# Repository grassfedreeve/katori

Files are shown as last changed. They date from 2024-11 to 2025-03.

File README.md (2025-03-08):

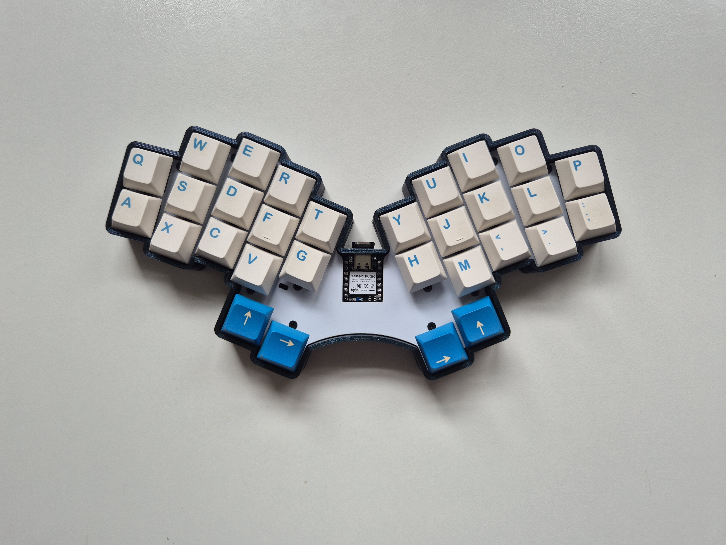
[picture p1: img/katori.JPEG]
katori


# katori
30-key wireless topre/ec hummingbird keyboard based on the [rufous](https://github.com/jcmkk3/trochilidae) & [topreviung](https://gitlab.com/lpgalaxy/topreviung) 
---- 
named after katori senkō mosquito coils that inspired the original conical spring design for topre switches, as well as katori's translation to bird as homage to the hummingbird.

## Status
Revision 1 has been built and tested. Had design error fixed in r2 but yet to be officially ordered

## Manufacturing

Can be hand soldered or ordered assembled using assembly files

Currently setup to use a 1.2mm aluminum single layer pcb as the plate

- [PCB production files](./production/)
- [Plate files](./plate/)
- [Case files](./case)

## Parts needed
- 1 pcb
- 1 plate
- 1 case
- 1 seeed xiao compatible controller
- 30 1u EC housing + slider
- 30 Rubber domes
- 30 Conical springs
- 26 [m1.6 5mm full thread standoffs](https://www.aliexpress.com/item/1005004397115309.html) 
- 1 [3x6x5 tht reset switch](https://www.aliexpress.com/store/1103739763)
- 26 m1.6 3mm screws
- 6 m3 3mm screws

## BOM
- 1 PCM12SMTR - power switch
- 7 SMTSO3020MTJ - SMD solder nut
- 2 TSSOP-16 multiplexers
- 1 0603 1k resistor
- 13 0603 100k resistors
- 3 0603 100n capacitors
- 1 0603 220pF capacitor

**Optional**
- Silencing rings
- [450mah 601148 battery](https://www.aliexpress.com/item/32844347206.html)
- 1 PCM12SMTR - power switch

#### PCB Renders
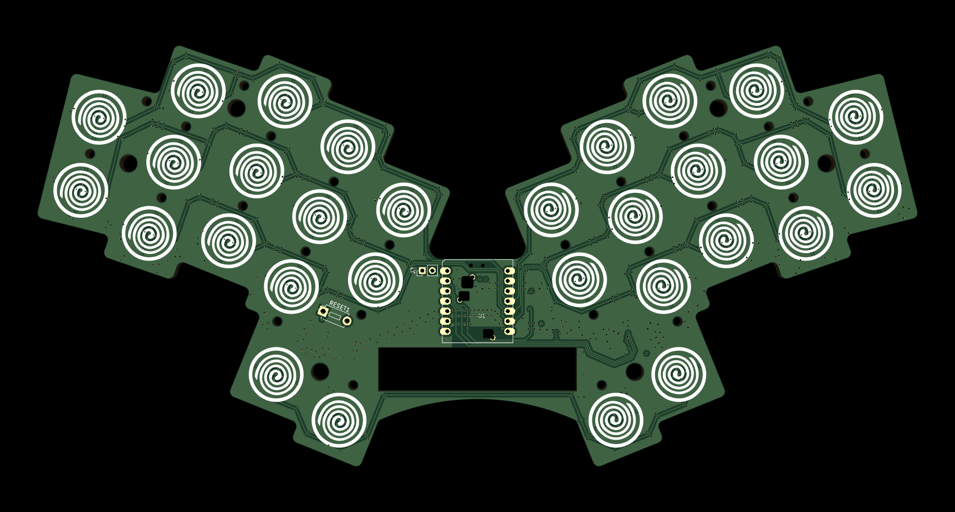
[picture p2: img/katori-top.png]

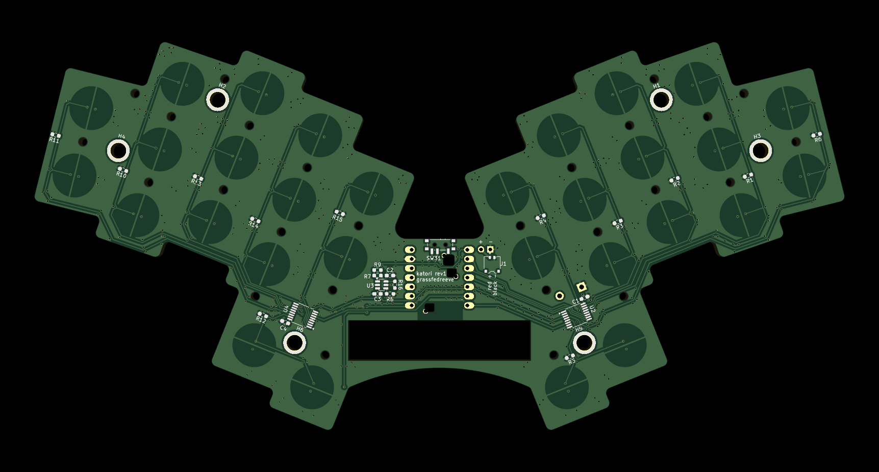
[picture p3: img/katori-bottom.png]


## Inspiration & Thanks
- jcmkk3's [rufous](https://github.com/jcmkk3/trochilidae#rufous) hummingbird variation, of which I used the Ergogen config and splay etc.
- pete johanson for his incredible help during the project and his [topreviung](https://gitlab.com/lpgalaxy/topreviung) keyboard, which was the basis of the schematic and entire EC portions.
- PJE66's original [hummingbird](https://github.com/PJE66/hummingbird) keyboard

## Acknowledgements 
Thank you to [PCBWay](https://www.pcbway.com/) for sponsoring this project!

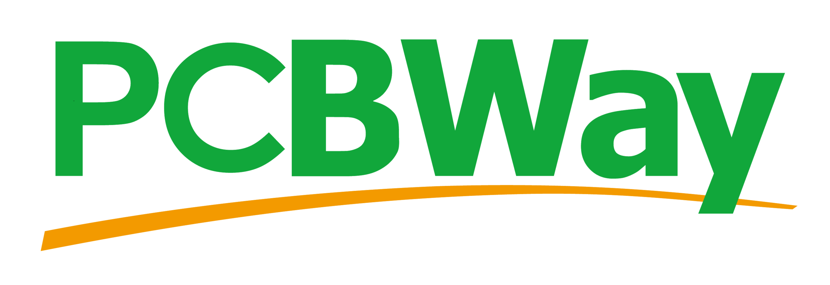
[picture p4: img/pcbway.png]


You can find and order the parts for this project on PCBWay using these links:

[pcb](https://www.pcbway.com/project/shareproject/Katori_30_key_wireless_topre_ec_hummingbird_keyboard_7163f60f.html)
[plate](https://www.pcbway.com/project/shareproject/Katori_Plate_a08691e4.html)

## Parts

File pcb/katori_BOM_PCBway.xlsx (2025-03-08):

 |  |  | xxxx xxxx xxxxx xxPCS BOM (Sample Bill of Materials)
Item # | *Designator | *Qty | Manufacturer | *Mfg Part # | Description / Value | *Package/Footprint | Type | Your Instructions / Notes
1 | J1 | 1 | JST | BM02B-ACHSS-GAN-ETF(LF)(SN) | 1x2P 2P ACH Gold 2 -25℃~+85℃ 2A 1 1.2mm Copper alloy Horizontal attachment SMD,P=1.2mm,Surface Mount，Right Angle Wire To Board Connector ROHS | SMD,P=1.2mm,Surface Mount，Right Angle | SMD
2 | U1 | 1 | Seeed-Studio | XIAO-BLE |  | SMD | DNS | DNP
3 | SW31 | 1 | C&K | PCM12SMTR | Standing paste Single Pole Double Throw (SPDT) 6V SMD Slide Switches ROHS | SMD | SMD
4 | H1,H2,H3,H4,H5,H6 | 7 | Sinhoo | SMTSO3020MTJ | SMD round nut | SMTSO3020MTJ | SMD
5 | U2,U4 | 2 | Texas Instruments | CD74HC4051PWR | TSSOP-16 Signal Switches, Multiplexers, Decoders ROHS | SSOP-16 | SMD
6 | R16 | 1 | UNI-ROYAL(Uniroyal Elec) | 0603WAF1004T5E | 100mW Thick Film Resistors 75V ±100ppm/℃ ±1% 1MΩ 0603 Chip Resistor - Surface Mount ROHS | 0603 | SMD | DNP
7 | R1,R2,R3,R4,R5,R6,R7,R10,R11,R12,R13,R14,R15 | 13 | UNI-ROYAL(Uniroyal Elec) | 0603WAF1003T5E | 100mW Thick Film Resistors 75V ±100ppm/℃ ±1% 100kΩ 0603 Chip Resistor - Surface Mount ROHS | 0603 | SMD
8 | R8 | 1 | UNI-ROYAL(Uniroyal Elec) | 0603WAF1001T5E | 100mW Thick Film Resistors 75V ±100ppm/℃ ±1% 1kΩ 0603 Chip Resistor - Surface Mount ROHS | 0603 | SMD
9 | C1,C2,C4 | 3 | Samsung Electro-Mechanics | CL10B104KB8NNNC | 50V 100nF X7R ±10% 0603 Multilayer Ceramic Capacitors MLCC - SMD/SMT ROHS | 0603 | SMD
10 | C3 | 1 | Samsung Electro-Mechanics | CL10B221KB8NNNC | 50V 220pF X7R ±10% 0603 Multilayer Ceramic Capacitors MLCC - SMD/SMT ROHS | 0603 | SMD
11 | U3 | 1 | Texas Instruments | OPA357AIDBVR | IC OPAMP VFB 1 CIRCUIT SOT23-6 | SOT-23-6 | SMD

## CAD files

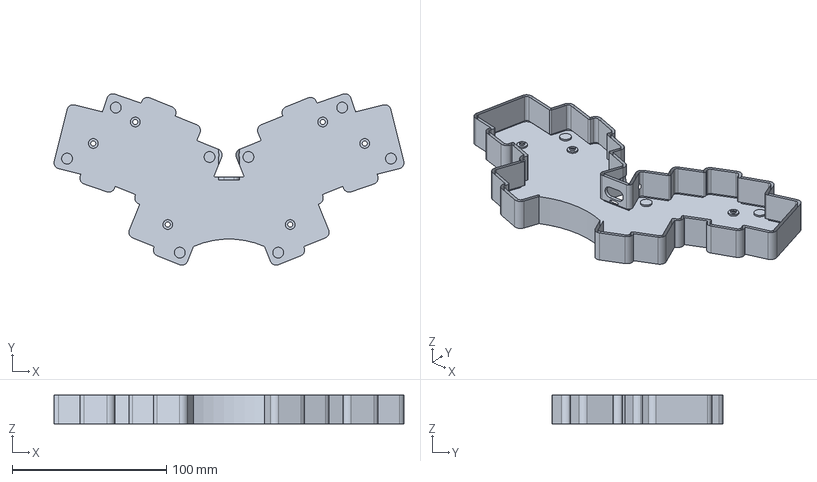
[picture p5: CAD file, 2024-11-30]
case/katori-case.step
226.9 x 111.1 x 18.6 mm

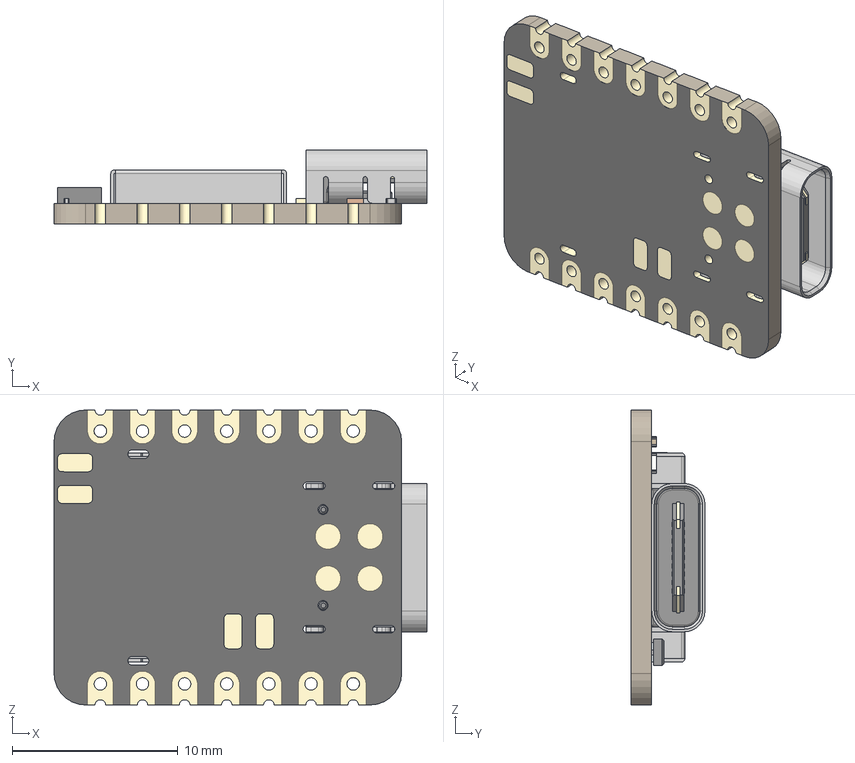
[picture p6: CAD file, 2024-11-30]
pcb/3d-models/XIAO-nRF52840 v15.step
22.5 x 4.46 x 17.8 mm
BOSS-EXTRUDE14_8_
BOSS-EXTRUDE7_4_
BOSS-EXTRUDE7_3_
BOSS-EXTRUDE14_4_
BOSS-EXTRUDE14_2_
BOSS-EXTRUDE14_11_
BOSS-EXTRUDE7_7_
BOSS-EXTRUDE14_9_
BOSS-EXTRUDE14_3_
BOSS-EXTRUDE14_7_
MIRROR2
BOSS-EXTRUDE14_5_
BOSS-EXTRUDE14_12_
BOSS-EXTRUDE7_8_
BOSS-EXTRUDE7_1_
BOSS-EXTRUDE14_10_
BOSS-EXTRUDE7_9_
BOSS-EXTRUDE14_6_
BOSS-EXTRUDE14_1_
BOSS-EXTRUDE7_6_
BOSS-EXTRUDE7_2_
CUT-EXTRUDE5
BOSS-EXTRUDE7_5_
Shield
Pins
CAP x 2
ANT1
Silkscreen
CAP 3
LED
USR
2 v1

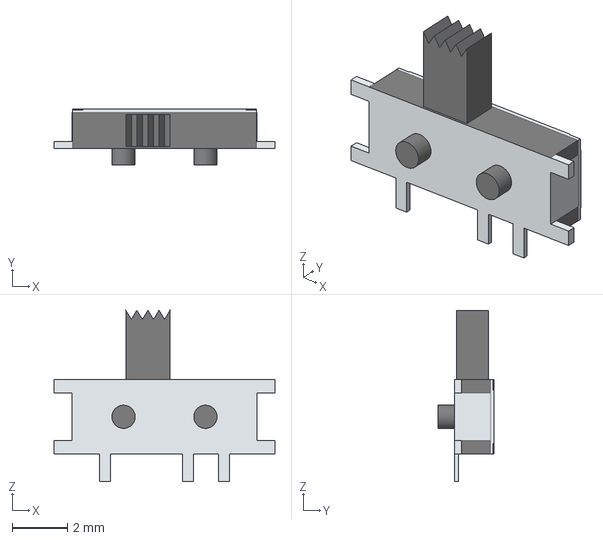
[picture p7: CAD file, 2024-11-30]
pcb/3d-models/Selector Switch - MSK1103.step
7.98 x 2.01 x 6.19 mm

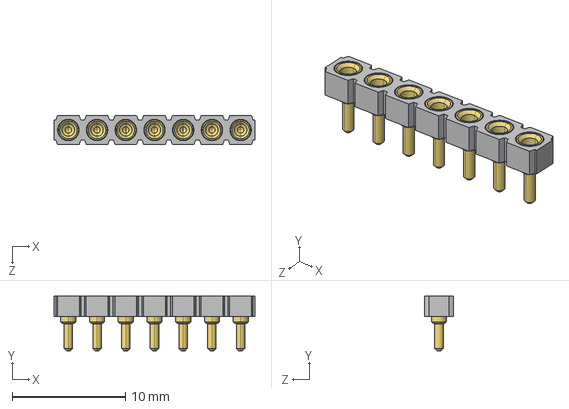
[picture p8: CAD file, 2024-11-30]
pcb/3d-models/mill-max-315-13-107-41-003000.STEP
17.8 x 4.83 x 2.54 mm
P3XX-11-011-00-000000_P307-11-011-00-000000

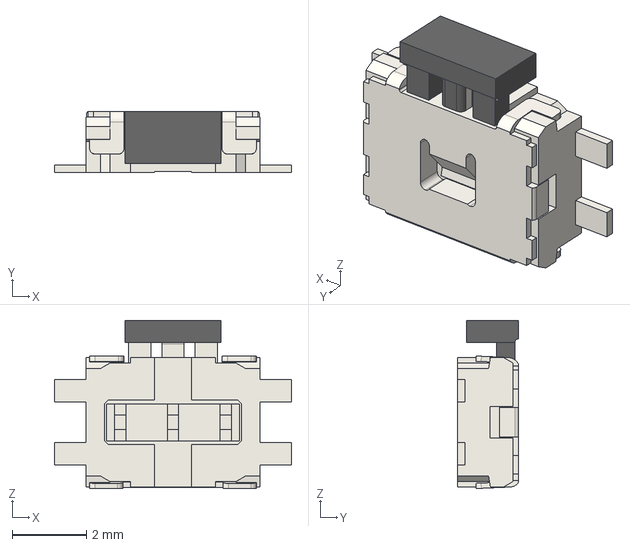
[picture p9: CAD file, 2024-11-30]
pcb/3d-models/EVQPU-JA-02K.STEP
6.40 x 1.65 x 4.54 mm

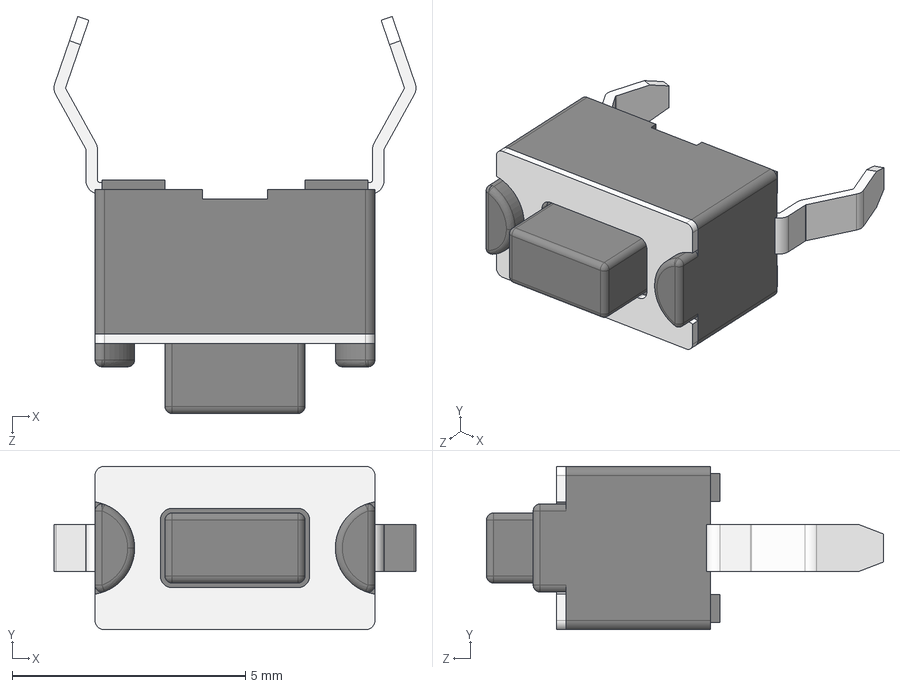
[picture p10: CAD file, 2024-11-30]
pcb/3d-models/3.5x6 THT.STEP
7.76 x 3.50 x 8.51 mm
Sheet Metal Part6 x 2

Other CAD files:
case/katori-case.stl

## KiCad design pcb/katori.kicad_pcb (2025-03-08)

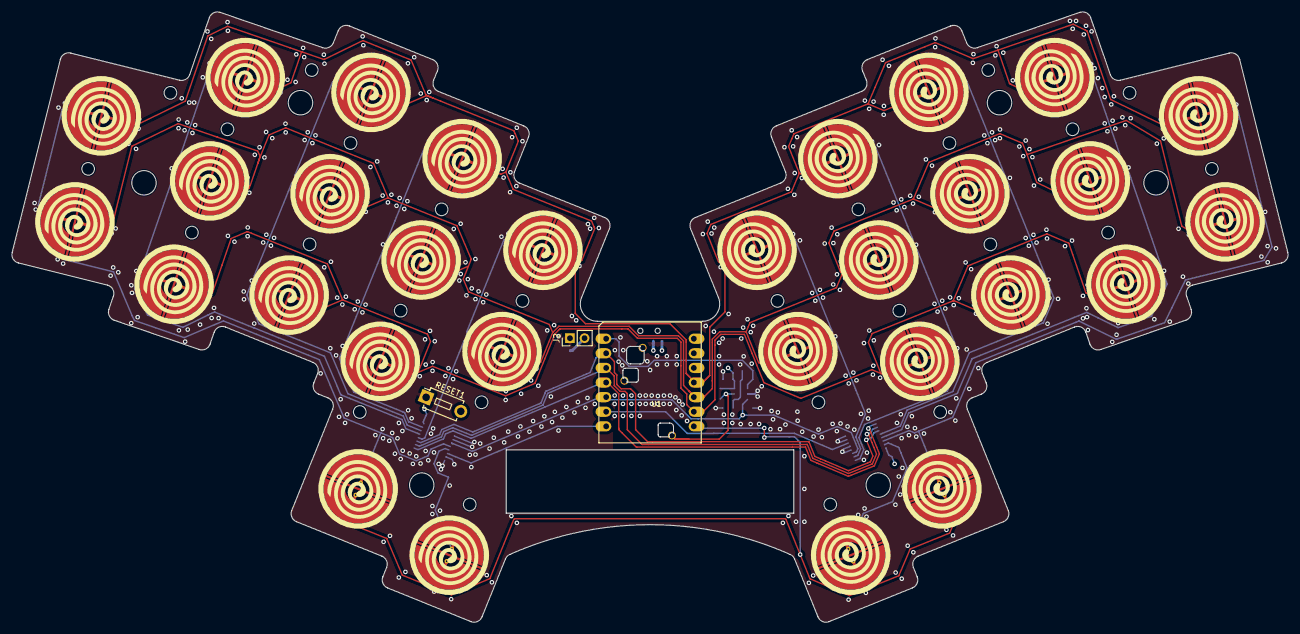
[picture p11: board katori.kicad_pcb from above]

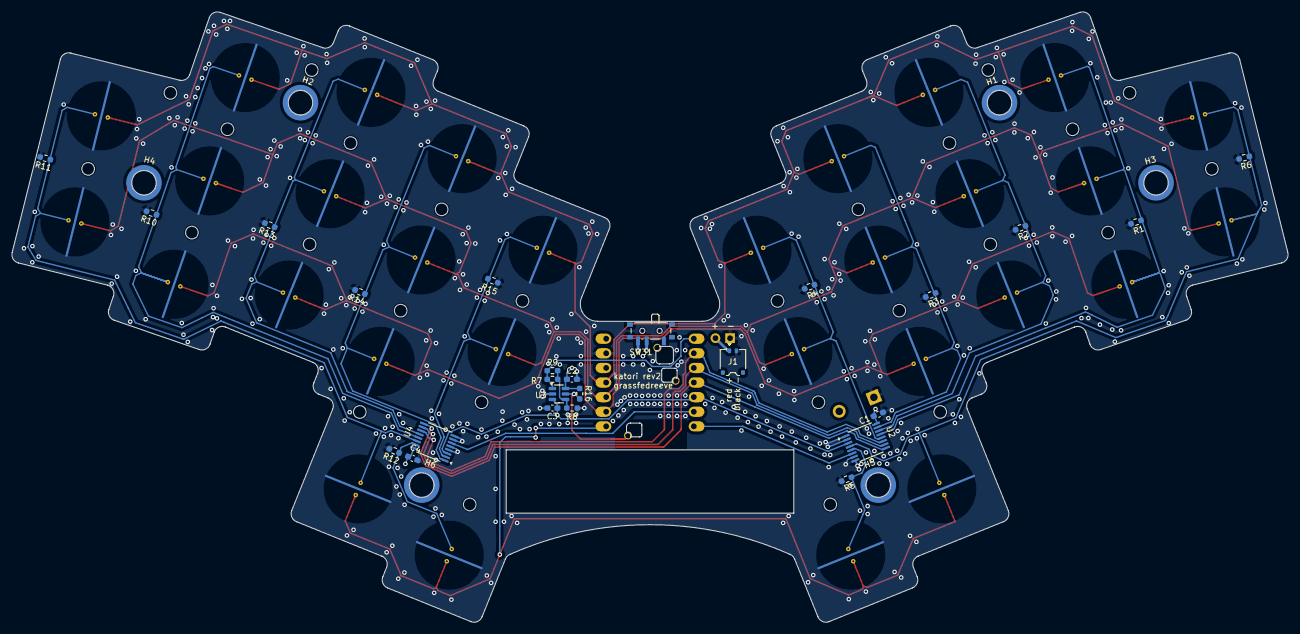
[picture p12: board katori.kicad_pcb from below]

Board: 4 copper layers, 221.9 x 106.1 mm, 98 parts (31 on the bottom side), 30 nets.

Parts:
BUMP1, BUMP2, BUMP3, BUMP4, BUMP5, BUMP6, BUMP7, BUMP8: MountingHole; Bumpon
C1, C2, C4: 100n; C_0603_1608Metric_Pad1.08x0.95mm_HandSolder
C3: 220pF; C_0603_1608Metric_Pad1.08x0.95mm_HandSolder
H1, H2, H3, H4, H5, H6: MountingHole; MountingHole_3mm_Pad_NonPTH_TopOnly
J1: JST ACH; JST_ACH_BM02B-ACHSS-GAN-ETF_1x02-1MP_P1.20mm_Vertical
J2: Solder; PinHeader_1x02_P2.54mm_Vertical
PH1, PH2, PH3, PH4, PH5, PH6, PH7, PH8, PH9, PH10, PH11, PH12, PH13, PH14, PH15, PH16, PH17, PH18, PH19, PH20, PH21, PH22, PH23, PH24, PH27, PH28: MountingHole; MountingHole_2.2mm_M2
R1, R2, R3, R4, R5, R6, R7, R10, R11, R12, R13, R14, R15: 100k; R_0603_1608Metric_Pad0.98x0.95mm_HandSolder
R8: 1k; R_0603_1608Metric_Pad0.98x0.95mm_HandSolder
R9: DNP; R_0603_1608Metric_Pad0.98x0.95mm_HandSolder
R16: 1M; R_0603_1608Metric_Pad0.98x0.95mm_HandSolder
RESET1: SW_PUSH; SW_PUSH_1P1T_6x3.5mm_H5.0_APEM_MJTP1250
SW1, SW2, SW3, SW4, SW5, SW6, SW7, SW8, SW9, SW10, SW11, SW12, SW13, SW14, SW15, SW16, SW17, SW18, SW19, SW20, SW21, SW22, SW23, SW24, SW25, SW26: EC_SW; katori_pad_1U_90deg
SW27, SW28, SW29, SW30: EC_SW; katori_pad_1U
SW31: POWER; SW_SPDT_PCM12
U1: SeeeduinoXIAO_Hybrid; xiao-ble-tht-cutout-topre-no-reset-outline
U2, U4: 74HC4051; TSSOP-16_4.4x5mm_P0.65mm
U3: OPA357AIDBVR; SOT-23-6

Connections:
+3V3: C1.2, C2.2, C4.2, R16.1, U1.12 (3V3), U2.16 (VCC), U3.6 (V+), U4.16 (VCC)
+BATT: SW31.3 (C), U1.16 (BAT+)
/BATT_RAW: J1.1, J2.2, SW31.2 (B)
/NRST: RESET1.2, U1.15 (RESET)
ADC: R7.1, R9.1, U1.1 (PA02_A0_D0), U3.1
ADC_ENABLE: R16.2, U1.17 (NFC1), U3.5 (ENABLE)
AMUX_SEL_0: U1.2 (PA4_A1_D1), U2.11 (S0), U4.11 (S0)
AMUX_SEL_1: U1.3 (PA10_A2_D2), U2.10 (S1), U4.10 (S1)
AMUX_SEL_2: U1.4 (PA11_A3_D3), U2.9 (S2), U4.9 (S2)
APLEX_EN0: U1.7 (PB08_A6_D6_TX), U2.6 (~E)
APLEX_EN1: U1.6 (PA9_A5_D5_SCL), U4.6 (~E)
APLEX_OUT: C3.1, U1.5 (PA8_A4_D4_SDA), U2.3 (A), U3.3 (+), U4.3 (A)
COL0: R6.1, SW1.1, SW11.1, SW27.2, U2.4 (A7)
COL1: R1.1, SW2.1, SW12.1, SW21.1, U2.13 (A0)
COL2: R2.1, SW3.1, SW13.1, SW22.1, U2.14 (A1)
COL3: R3.1, SW4.1, SW14.1, SW23.1, U2.15 (A2)
COL4: R4.1, SW5.1, SW15.1, U2.12 (A3)
COL5: R15.1, SW6.1, SW16.1, U4.2 (A6)
COL6: R14.1, SW7.1, SW17.1, SW24.1, U4.1 (A4)
COL7: R13.1, SW8.1, SW18.1, SW25.1, U4.12 (A3)
COL8: R10.1, SW9.1, SW19.1, SW26.1, U4.13 (A0)
COL9: R11.1, SW10.1, SW20.1, SW30.1, U4.14 (A1)
COL10: R5.1, SW28.2, U2.5 (A5)
COL11: R12.1, SW29.1, U4.15 (A2)
GND: C1.1, C2.1, C3.2, C4.1, J1.2, J2.1, R1.2, R2.2, R3.2, R4.2, R5.2, R6.2, R8.2, R10.2, R11.2, R12.2, R13.2, R14.2, R15.2, RESET1.1, SW1.3 (SG), SW2.3 (SG), SW3.3 (SG), SW4.3 (SG), SW5.3 (SG), SW6.3 (SG), SW7.3 (SG), SW8.3 (SG), SW9.3 (SG), SW10.3 (SG), SW11.3 (SG), SW12.3 (SG), SW13.3 (SG), SW14.3 (SG), SW15.3 (SG), SW16.3 (SG), SW17.3 (SG), SW18.3 (SG), SW19.3 (SG), SW20.3 (SG), SW21.3 (SG), SW22.3 (SG), SW23.3 (SG), SW24.3 (SG), SW25.3 (SG), SW26.3 (SG), SW27.3 (SG), SW28.3 (SG), SW29.3 (SG), SW30.3 (SG), U1.13 (GND), U2.1 (A4), U2.2 (A6), U2.7 (VEE), U2.8 (GND), U3.2 (V-), U4.4 (A7), U4.5 (A5), U4.7 (VEE), U4.8 (GND)
unnamed: R7.2, R8.1, R9.2, U3.4 (-)
ROW0: SW1.2, SW2.2, SW3.2, SW4.2, SW5.2, SW6.2, SW7.2, SW8.2, SW9.2, SW10.2, U1.11 (PA6_A10_D10_MOSI)
ROW1: SW11.2, SW12.2, SW13.2, SW14.2, SW15.2, SW16.2, SW17.2, SW18.2, SW19.2, SW20.2, U1.10 (PA5_A9_D9_MISO)
ROW2: SW21.2, SW22.2, SW23.2, SW24.2, SW25.2, SW26.2, U1.9 (PA7_A8_D8_SCK)
ROW3: SW27.1, SW28.1, SW29.2, SW30.2, U1.8 (PB09_A7_D7_RX)

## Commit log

2024-11-30 initial commit after cleanup
    [3.5x6 THT.STEP, EVQPU-JA-02K.STEP, Selector Switch - MSK1103.step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]
2024-12-21 update bom
    [katori_BOM_PCBway.xlsx]
2025-03-08 revision 2 and readme updates
    [katori-B_Cu.gbr, katori-B_Mask.gbr, katori-B_Paste.gbr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]
